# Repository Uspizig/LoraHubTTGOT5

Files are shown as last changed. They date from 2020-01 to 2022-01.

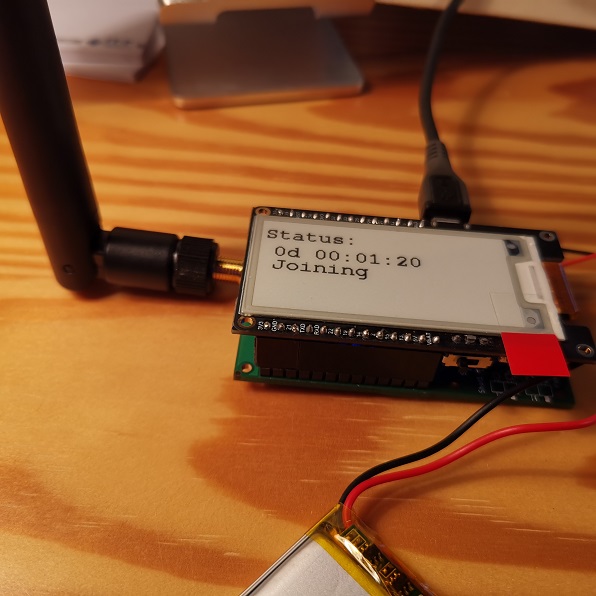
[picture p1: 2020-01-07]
Images/klein_IMG_20200107_193522.jpg

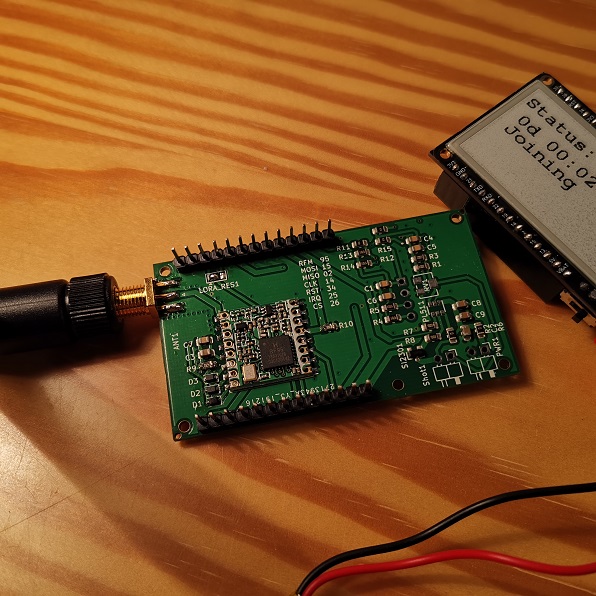
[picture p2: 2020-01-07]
Images/klein_IMG_20200107_193700.jpg

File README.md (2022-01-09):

# LoraHubTTGOT5
Please keep in mind. There are some Limitations in the TTn network right now:
1. For usage with TTN V3: Pease consider this change to avoid unwanted Downlink messages. https://github.com/mcci-catena/arduino-lmic/issues/713 

(Prerequisite: This is my Hobby: No Guarantee for HW or SW. I do not take any responsibility or will help you. This is: "Take it as it is or leave it".)
DO NOT USE THIS in ANY COMMERCIAL PRODUCTS

A LORA TTN Daughter Board for a TTGO T5 Board (http://s.click.aliexpress.com/e/NPRqgBkG) with BME680, BME280, CCS811 and connection possibilities for several other I²C Boards

You might have seen several E-Ink Boards from Waveshare lately. I came across some Boards from TTGO with an ESP32 lately on Aliexpress.
While experimenting with these Boards I tought: Why not add a LORA TTN Chip to these Boards and some other environment sensors.

So here is my try:

You may find in this Repository:
1. Hardware: KiCad & Gerber Files for 
2. SMT Assembly Files for jlcPCB 
3. Pinning: Pin Description
4. Software: A how to make these things running relatively easy in an Arduino IDE

What you need to do to get the SW Running:
1. Clone this Git: https://github.com/ZinggJM/GxEPD2 and install to your Arduino lib folder
2. Replace the two files with the ones provided in GxEPDReplace
3. Install: https://github.com/thesolarnomad/lora-serialization
4. Clone this Git: https://github.com/mcci-catena/arduino-lmic
5A. Make the modifications mentioned in otta SW
5B. Edidt config in the MCCI-Catena to set according yoru Country.
6. Get an App ID, from Thethingsnetwork
7. Check if your area has LORA TTN Coverage
8. Try out one of the examples.

What you need to get the HW:
- TTGO T5 EPaper Board: https://de.aliexpress.com/item/32869729970.html
- RFM95 Lora Chip: https://de.aliexpress.com/item/32831799362.html
- Antenna Connector SMA: http://s.click.aliexpress.com/e/5oGOCiY0
- (OPTIONAL)8dBi Antenna 868MHz: http://s.click.aliexpress.com/e/KVkmsTGG
- (OPTIONAL)TPL5110 for Low Power: http://s.click.aliexpress.com/e/EA7q1R48
- Spacer-Screws: http://s.click.aliexpress.com/e/KejkugSM

Hub Board:
1. Download the Gerber and BOM Files
2. Upload to JLCPCB
3. Select SMT Assembly
4. Solder 3 Diodes, Antenna Connector and RFM Module on the Board
5. (Optional): Solder Battery Connector and TPL5110 Chip on the Board.
6. I made a mistake on the FET and switched Drain and Source pin. You need to make a air wire to fix this if you want to use the TPL5110 RTC.

What you need to Solder
1. RFM95 Chip
2. Antenna Connector
3. 3x Diodes
(Optional) TPL5110 Chip and Battery Connector

Housings:
https://www.thingiverse.com/thing:3462483
https://www.thingiverse.com/thing:4055993

Useful Equipment.:
- Soldering Iron TS100: http://s.click.aliexpress.com/e/Eq2v9g12
- USB Cable: http://s.click.aliexpress.com/e/NiloJfUM
- Soldering Mat. http://s.click.aliexpress.com/e/NAoYAQ5K

My projects are influenced by Dave(G6EJD) and Andreas Spiess. So do me a favor and watch their videos.

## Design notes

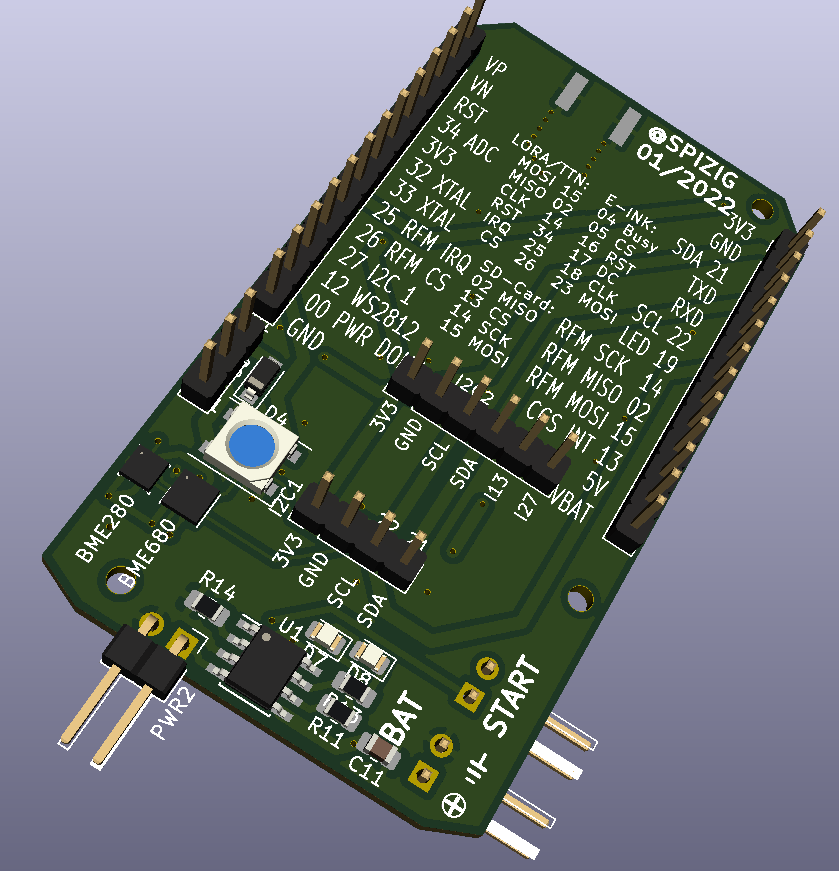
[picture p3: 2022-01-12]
ttgot5 - v2/front.PNG

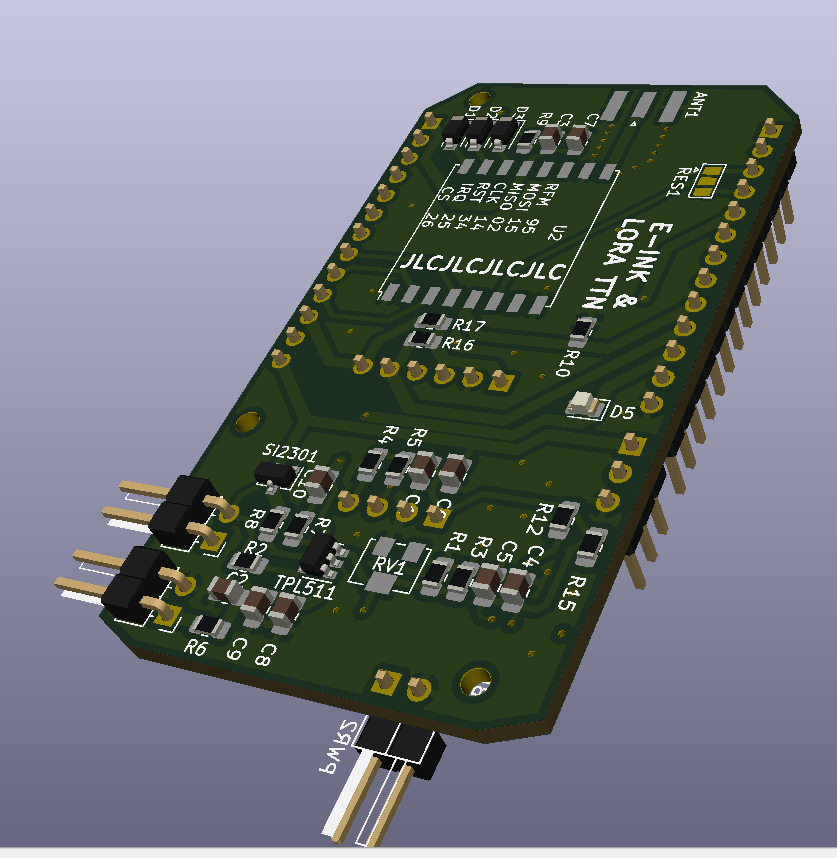
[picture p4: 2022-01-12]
ttgot5 - v2/back.PNG

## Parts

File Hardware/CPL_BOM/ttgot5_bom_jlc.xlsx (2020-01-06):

Comment | Designator | Footprint | LCSC Part #（optional）
100nF | C1 | 0805_C | C49678 (https://lcsc.com/product-detail/Multilayer-Ceramic-Capacitors-MLCC-SMD-SMT_100nF-104-10-50V_C49678.html/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)
22uF | C2 | 0805_C | C45783 (https://lcsc.com/product-detail/Multilayer-Ceramic-Capacitors-MLCC-SMD-SMT_SAMSUNG_CL21A226MAQNNNE_22uF-226-20-25V_C45783.html/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)
1uF | C3 | 0805_C | C28323 (https://lcsc.com/product-detail/Multilayer-Ceramic-Capacitors-MLCC-SMD-SMT_SAMSUNG_CL21B105KBFNNNE_1uF-105-10-50V_C28323.html/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)
100nF | C4 | 0805_C | C49678 (https://lcsc.com/product-detail/Multilayer-Ceramic-Capacitors-MLCC-SMD-SMT_100nF-104-10-50V_C49678.html/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)
100nF | C5 | 0805_C | C49678 (https://lcsc.com/product-detail/Multilayer-Ceramic-Capacitors-MLCC-SMD-SMT_100nF-104-10-50V_C49678.html/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)
100nF | C6 | 0805_C | C49678 (https://lcsc.com/product-detail/Multilayer-Ceramic-Capacitors-MLCC-SMD-SMT_100nF-104-10-50V_C49678.html/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)
100nF | C7 | 0805_C | C49678 (https://lcsc.com/product-detail/Multilayer-Ceramic-Capacitors-MLCC-SMD-SMT_100nF-104-10-50V_C49678.html/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)
1uF | C8 | 0805_C | C28323 (https://lcsc.com/product-detail/Multilayer-Ceramic-Capacitors-MLCC-SMD-SMT_SAMSUNG_CL21B105KBFNNNE_1uF-105-10-50V_C28323.html/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)
100nF | C9 | 0805_C | C28323 (https://lcsc.com/product-detail/Multilayer-Ceramic-Capacitors-MLCC-SMD-SMT_SAMSUNG_CL21B105KBFNNNE_1uF-105-10-50V_C28323.html/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)
1N5819WS | D1 | SOD-323 | C191023 (https://lcsc.com/product-detail/Others_B5819WS_C191023.html/?href=jlc-SMT)
1N5819WS | D2 | SOD-323 | C191023 (https://lcsc.com/product-detail/Others_B5819WS_C191023.html/?href=jlc-SMT)
1N5819WS | D3 | SOD-323 | C191023 (https://lcsc.com/product-detail/Others_B5819WS_C191023.html/?href=jlc-SMT)
TPL5110DDCT | PL511 | TSOT-23-6 | C125830 (https://lcsc.com/product-detail/Timer_TI_TPL5110DDCT_TPL5110DDCT_C125830.html/?href=jlc-SMT)
200K | R1 | 0805_R | C17539 (https://lcsc.com/product-detail/Chip-Resistor-Surface-Mount_Uniroyal-Elec-0805W8F2003T5E_C17539.html/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)
0R | R2 | 0805_R | C17477 (https://lcsc.com/product-detail/Chip-Resistor-Surface-Mount_Uniroyal-Elec-0805W8F0000T5E_C17477.html/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)
200K | R3 | 0805_R | C17539 (https://lcsc.com/product-detail/Chip-Resistor-Surface-Mount_Uniroyal-Elec-0805W8F2003T5E_C17539.html/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)
4.7K | R4 | 0805_R | C17673 (https://lcsc.com/product-detail/Chip-Resistor-Surface-Mount_Uniroyal-Elec-0805W8F4701T5E_C17673.html/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)
4.7K | R5 | 0805_R | C17673 (https://lcsc.com/product-detail/Chip-Resistor-Surface-Mount_Uniroyal-Elec-0805W8F4701T5E_C17673.html/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)
0R | R6 | 0805_R | C17477 (https://lcsc.com/product-detail/Chip-Resistor-Surface-Mount_Uniroyal-Elec-0805W8F0000T5E_C17477.html/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)
100K | R7 | 0805_R | C17407 (https://lcsc.com/product-detail/Chip-Resistor-Surface-Mount_Uniroyal-Elec-0805W8F1003T5E_C17407.html/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)
100K | R8 | 0805_R | C17407 (https://lcsc.com/product-detail/Chip-Resistor-Surface-Mount_Uniroyal-Elec-0805W8F1003T5E_C17407.html/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)
100K | R9 | 0805_R | C17407 (https://lcsc.com/product-detail/Chip-Resistor-Surface-Mount_Uniroyal-Elec-0805W8F1003T5E_C17407.html/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)
100K | R10 | 0805_R | C17407 (https://lcsc.com/product-detail/Chip-Resistor-Surface-Mount_Uniroyal-Elec-0805W8F1003T5E_C17407.html/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)
0R | R11 | 0805_R | C17477 (https://lcsc.com/product-detail/Chip-Resistor-Surface-Mount_Uniroyal-Elec-0805W8F0000T5E_C17477.html/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)
0R | R12 | 0805_R | C17477 (https://lcsc.com/product-detail/Chip-Resistor-Surface-Mount_Uniroyal-Elec-0805W8F0000T5E_C17477.html/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)
4.7K | R13 | 0805_R | C17673 (https://lcsc.com/product-detail/Chip-Resistor-Surface-Mount_Uniroyal-Elec-0805W8F4701T5E_C17673.html/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)
4.7K | R14 | 0805_R | C17673 (https://lcsc.com/product-detail/Chip-Resistor-Surface-Mount_Uniroyal-Elec-0805W8F4701T5E_C17673.html/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)
0R | R15 | 0805_R | C17477 (https://lcsc.com/product-detail/Chip-Resistor-Surface-Mount_Uniroyal-Elec-0805W8F0000T5E_C17477.html/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)
SI2301CDS-T1-GE3 | SI2301 | SOT-23-3 | C10487 (https://lcsc.com/product-detail/MOSFET_Vishay-Intertech_SI2301CDS-T1-GE3_Vishay-Intertech-SI2301CDS-T1-GE3_C10487.html/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)

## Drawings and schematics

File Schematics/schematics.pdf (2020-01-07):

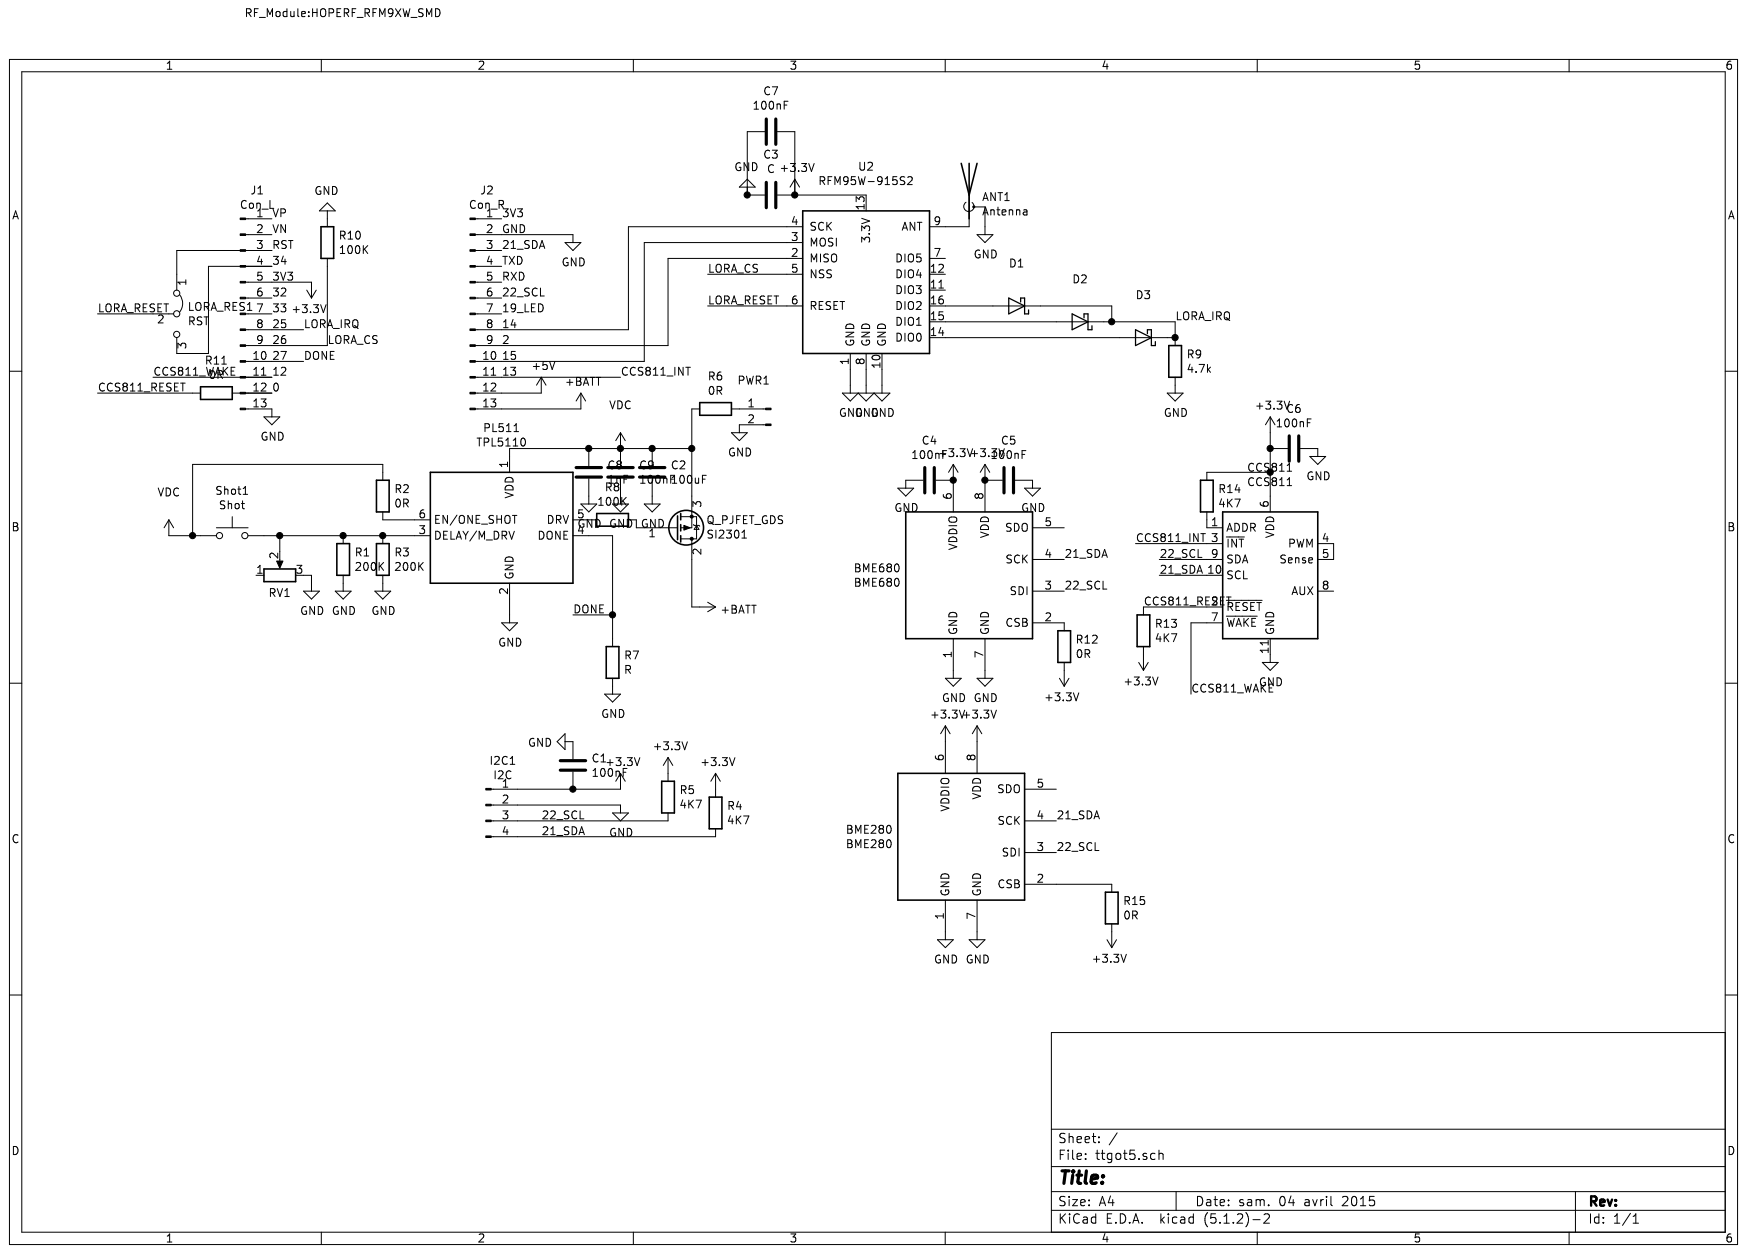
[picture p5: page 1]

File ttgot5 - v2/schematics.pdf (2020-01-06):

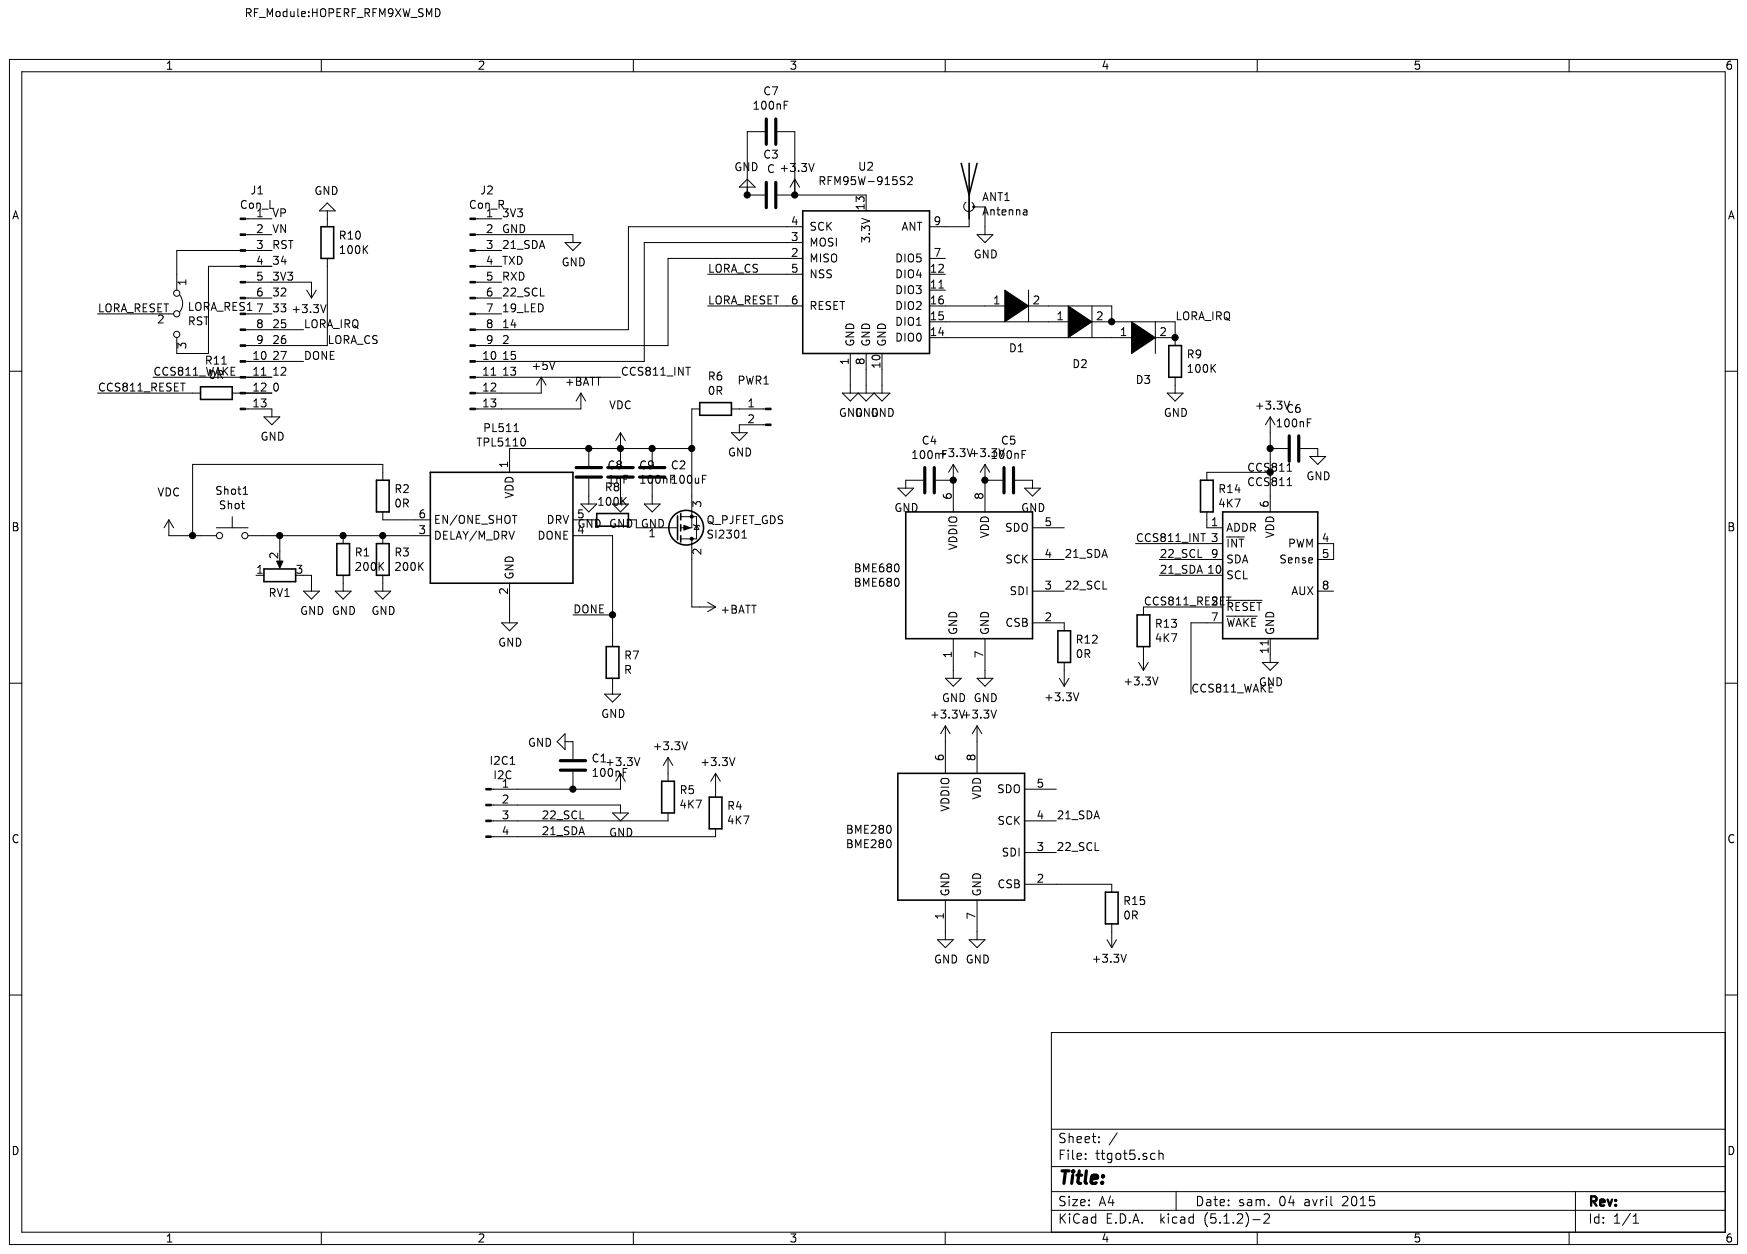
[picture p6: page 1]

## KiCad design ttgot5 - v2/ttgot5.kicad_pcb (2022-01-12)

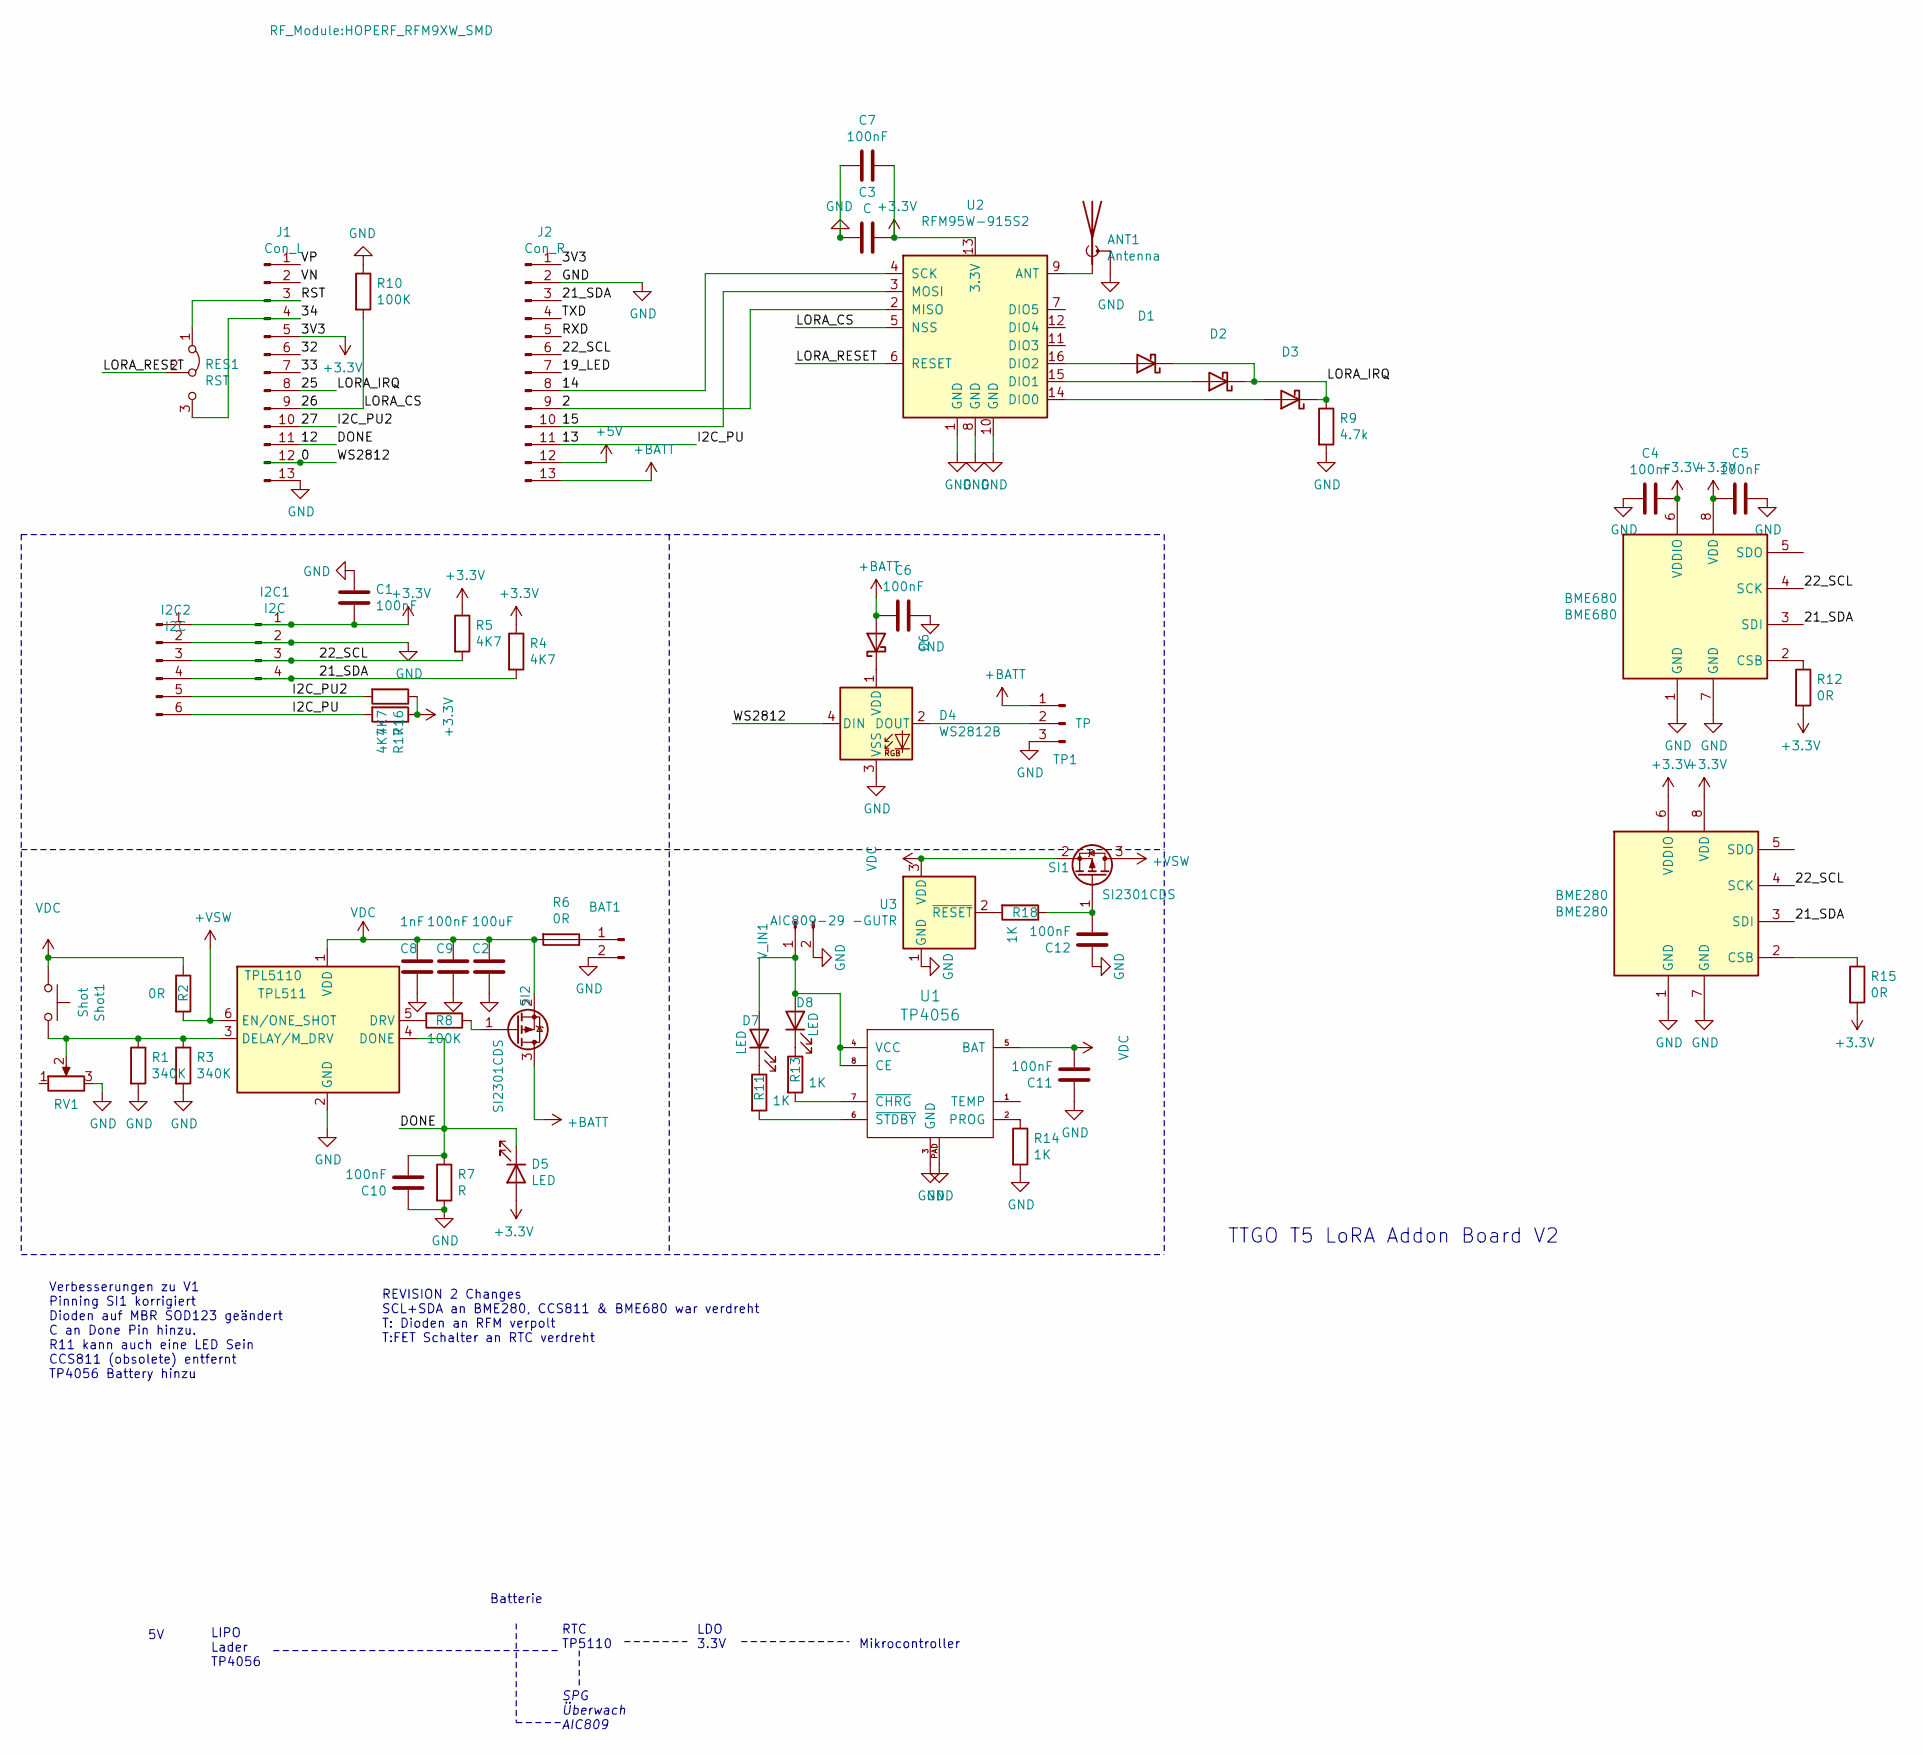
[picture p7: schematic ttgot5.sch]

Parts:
ANT1: Antenna; SMA_Samtec_SMA-J-P-H-ST-EM1_EdgeMount
BAT1: PWR; PinHeader_1x02_P2.54mm_Horizontal
BME280: BME280; Bosch_LGA-8_2.5x2.5mm_P0.65mm_ClockwisePinNumbering
BME680: BME680; Bosch_LGA-8_3x3mm_P0.8mm_ClockwisePinNumbering
C1, C4, C5, C6, C7, C9, C10, C11, C12: 100nF; C_0805_2012Metric_Pad1.15x1.40mm_HandSolder
C2: 100uF; C_0805_2012Metric_Pad1.15x1.40mm_HandSolder
C3: C; C_0805_2012Metric_Pad1.15x1.40mm_HandSolder
C8: 1nF; C_0805_2012Metric_Pad1.15x1.40mm_HandSolder
D1, D2, D3, D6: D; D_SOD-123
D4: WS2812B; LED_WS2812B_PLCC4_5.0x5.0mm_P3.2mm
D5, D7, D8: LED; LED_0805_2012Metric
I2C1: I2C; PinHeader_1x04_P2.54mm_Vertical
I2C2: I2C; PinHeader_1x06_P2.54mm_Vertical
J1: Con_L; PinHeader_1x13_P2.54mm_Vertical
J2: Con_R; PinHeader_1x13_P2.54mm_Vertical
R1, R3: 340K; R_0805_2012Metric_Pad1.15x1.40mm_HandSolder
R2, R6, R12, R15: 0R; R_0805_2012Metric_Pad1.15x1.40mm_HandSolder
R4, R5, R16, R17: 4K7; R_0805_2012Metric_Pad1.15x1.40mm_HandSolder
R7: R; R_0805_2012Metric_Pad1.15x1.40mm_HandSolder
R8, R10: 100K; R_0805_2012Metric_Pad1.15x1.40mm_HandSolder
R9: 4.7k; R_0805_2012Metric_Pad1.15x1.40mm_HandSolder
R11, R13, R14, R18: 1K; R_0805_2012Metric_Pad1.15x1.40mm_HandSolder
RES1: RST; SolderJumper-3_P1.3mm_Bridged12_Pad1.0x1.5mm
RV1: R_POT; Potentiometer_Bourns_3224W_Vertical
SI1, SI2: SI2301CDS; SOT-23
Shot1: Shot; PinHeader_1x02_P2.54mm_Horizontal
TP1: TP; PinHeader_1x03_P2.54mm_Vertical
TPL511: TPL5110; SOT-23-6
U1: TP4056; tp4056
U2: RFM95W-915S2; HOPERF_RFM9XW_SMD
U3: AIC809-29 -GUTR; SOT-23
V_IN1: PWR; PinHeader_1x02_P2.54mm_Horizontal

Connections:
+3V3: BME280.6 (VDDIO), BME280.8 (VDD), BME680.6 (VDDIO), BME680.8 (VDD), C1.2, C3.2, C4.1, C5.2, C7.2, D5.2 (A), I2C1.1, I2C2.1, J1.5, J2.1, R4.1, R5.1, R12.2, R15.2, R16.1, R17.1, U2.13 (3.3V)
+5V: J2.12
+BATT: C6.2, D6.2 (A), J2.13, SI2.3 (D), TP1.1
+VSW: R2.2, SI1.3 (D), TPL511.6 (EN/ONE_SHOT)
/0: D4.4 (DIN), J1.12
/2: J2.9, U2.2 (MISO)
/12: C10.2, D5.1 (K), J1.11, R7.1, TPL511.4 (DONE)
/13: I2C2.6, J2.11, R17.2
/14: J2.8, U2.4 (SCK)
/15: J2.10, U2.3 (MOSI)
/19_LED: J2.7
/21_SDA: BME280.3 (SDI), BME680.3 (SDI), I2C1.4, I2C2.4, J2.3, R4.2
/22_SCL: BME280.4 (SCK), BME680.4 (SCK), I2C1.3, I2C2.3, J2.6, R5.2
/25: D1.1 (K), D2.1 (K), D3.1 (K), J1.8, R9.1
/26: J1.9, R10.2, U2.5 (NSS)
/27: I2C2.5, J1.10, R16.2
/32: J1.6
/33: J1.7
/34: J1.4, RES1.3 (B)
/LORA_RESET: RES1.2 (C), U2.6 (RESET)
/RST: J1.3, RES1.1 (A)
/RXD: J2.5
/TXD: J2.4
/VN: J1.2
/VP: J1.1
GND: ANT1.2 (Shield), BAT1.2, BME280.1 (GND), BME280.7 (GND), BME680.1 (GND), BME680.7 (GND), C1.1, C2.2, C3.1, C4.2, C5.1, C6.1, C7.1, C8.2, C9.2, C10.1, C11.1, C12.1, D4.3 (VSS), I2C1.2, I2C2.2, J1.13, J2.2, R1.2, R3.2, R7.2, R9.2, R10.1, R14.2, RV1.3, TP1.3, TPL511.2 (GND), U1.3 (GND), U1.PAD, U2.1 (GND), U2.8 (GND), U2.10 (GND), U3.1 (GND), V_IN1.2
unnamed: ANT1.1 (A), U2.9 (ANT)
unnamed: BAT1.1, R6.1
unnamed: BME280.2 (CSB), R15.1
unnamed: BME680.2 (CSB), R12.1
unnamed: C12.2, R18.1, SI1.1 (G)
unnamed: D1.2 (A), U2.16 (DIO2)
unnamed: D2.2 (A), U2.15 (DIO1)
unnamed: D3.2 (A), U2.14 (DIO0)
unnamed: D4.1 (VDD), D6.1 (K)
unnamed: D4.2 (DOUT), TP1.2
unnamed: D7.1 (K), R11.1
unnamed: D7.2 (A), D8.2 (A), U1.4 (VCC), U1.8 (CE), V_IN1.1
unnamed: D8.1 (K), R13.1
unnamed: R1.1, R3.1, RV1.2, Shot1.1, TPL511.3 (DELAY/M_DRV)
unnamed: R8.1, SI2.1 (G)
unnamed: R8.2, TPL511.5 (DRV)
unnamed: R11.2, U1.6 (~STDBY)
unnamed: R13.2, U1.7 (~CHRG)
unnamed: R14.1, U1.2 (PROG)
unnamed: R18.2, U3.2 (~RESET)
VDC: C2.1, C8.1, C9.1, C11.2, R2.1, R6.2, SI1.2 (S), SI2.2 (S), Shot1.2, TPL511.1 (VDD), U1.5 (BAT), U3.3 (VDD)

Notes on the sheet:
REVISION 2 Changes SCL+SDA an BME280, CCS811 & BME680 war verdreht T: Dioden an RFM verpolt T:FET Schalter an RTC verdreht
Verbesserungen zu V1 Pinning SI1 korrigiert Dioden auf MBR SOD123 geändert C an Done Pin hinzu. R11 kann auch eine LED Sein CCS811 (obsolete) entfernt TP4056 Battery hinzu
TTGO T5 LoRA Addon Board V2
LIPO Lader TP4056
SPG Überwach AIC809
RTC TP5110
LDO 3.3V
Mikrocontroller
Batterie

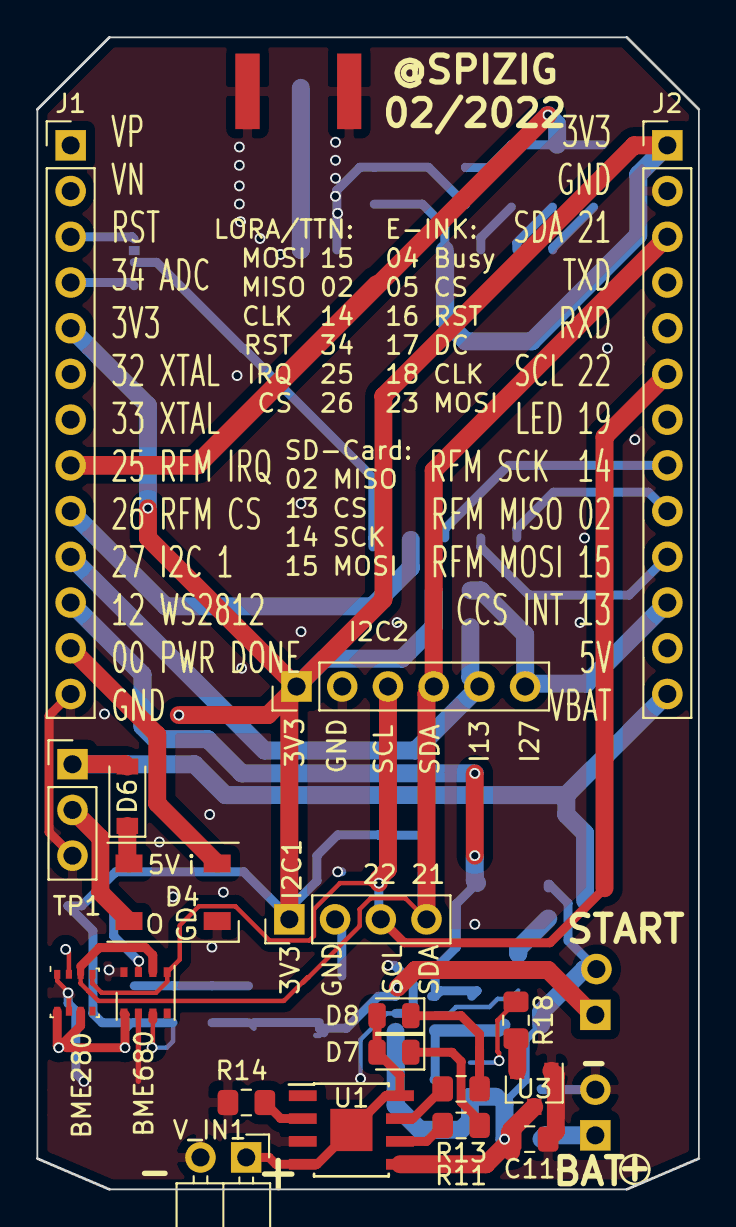
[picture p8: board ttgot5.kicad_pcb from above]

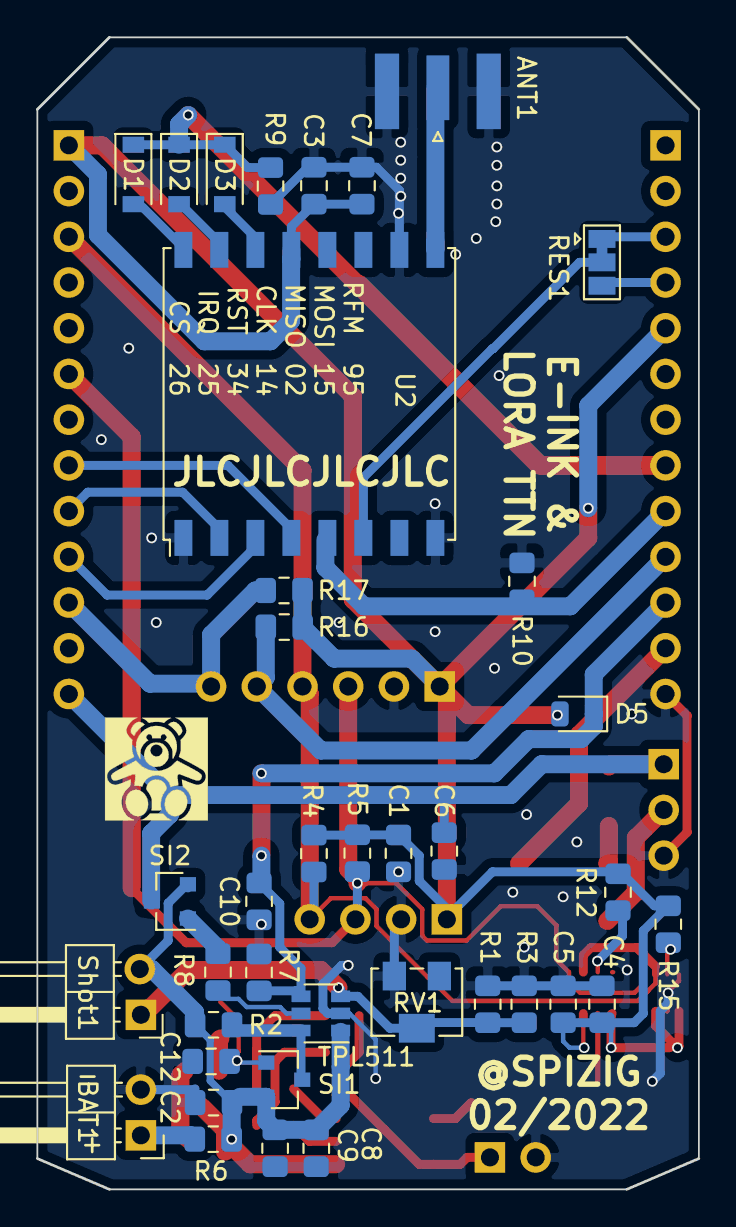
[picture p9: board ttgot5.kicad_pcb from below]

Board: 2 copper layers, 36.8 x 64.0 mm, 57 parts (38 on the bottom side), 39 nets.

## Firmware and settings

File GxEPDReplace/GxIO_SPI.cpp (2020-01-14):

// created by Jean-Marc Zingg to be the GxIO_SPI io class for the GxEPD library
//
// License: GNU GENERAL PUBLIC LICENSE V3, see LICENSE
//

#include "GxIO_SPI.h"

#if defined(PARTICLE)
// transfer16 is not used by GxEPD
#define transfer16 transfer
#endif

#ifdef TTGOT5
GxIO_SPI::GxIO_SPI(SPIClass& einkspi, int8_t cs, int8_t dc, int8_t rst, int8_t bl) :
  _spi(einkspi), _spi_settings(4000000, MSBFIRST, SPI_MODE0),
  _cs(cs), _dc(dc), _rst(rst), _bl(bl)
#else
GxIO_SPI::GxIO_SPI(SPIClass& spi, int8_t cs, int8_t dc, int8_t rst, int8_t bl) :
  _spi(spi), _spi_settings(4000000, MSBFIRST, SPI_MODE0),
  _cs(cs), _dc(dc), _rst(rst), _bl(bl)
{
}
#endif


void GxIO_SPI::reset()
{
  if (_rst >= 0)
  {
    delay(20);
    digitalWrite(_rst, LOW);
    delay(20);
    digitalWrite(_rst, HIGH);
    delay(200);
  }
}

void GxIO_SPI::init()
{
  if (_cs >= 0)
  {
    digitalWrite(_cs, HIGH);
    pinMode(_cs, OUTPUT);
  }
  if (_dc >= 0)
  {
    digitalWrite(_dc, HIGH);
    pinMode(_dc, OUTPUT);
  }
  if (_rst >= 0)
  {
    digitalWrite(_rst, HIGH);
    pinMode(_rst, OUTPUT);
  }
  if (_bl >= 0)
  {
    digitalWrite(_bl, HIGH);
    pinMode(_bl, OUTPUT);
  }
  reset();
  _spi.begin();
}

void GxIO_SPI::setFrequency(uint32_t freq)
{
  _spi_settings = SPISettings(freq, MSBFIRST, SPI_MODE0);
}

uint8_t GxIO_SPI::transferTransaction(uint8_t d)
{
  _spi.beginTransaction(_spi_settings);
  if (_cs >= 0) digitalWrite(_cs, LOW);
  uint8_t rv = _spi.transfer(d);
  if (_cs >= 0) digitalWrite(_cs, HIGH);
  _spi.endTransaction();
  return rv;
}

uint16_t GxIO_SPI::transfer16Transaction(uint16_t d)
{
  _spi.beginTransaction(_spi_settings);
  if (_cs >= 0) digitalWrite(_cs, LOW);
  uint16_t rv = _spi.transfer16(d);
  if (_cs >= 0) digitalWrite(_cs, HIGH);
  _spi.endTransaction();
  return rv;
}

uint8_t GxIO_SPI::readDataTransaction()
{
  _spi.beginTransaction(_spi_settings);
  if (_cs >= 0) digitalWrite(_cs, LOW);
  uint8_t rv = _spi.transfer(0xFF);
  if (_cs >= 0) digitalWrite(_cs, HIGH);
  _spi.endTransaction();
  return rv;
}

uint16_t GxIO_SPI::readData16Transaction()
{
  _spi.beginTransaction(_spi_settings);
  if (_cs >= 0) digitalWrite(_cs, LOW);
  uint16_t rv = _spi.transfer16(0xFFFF);
  if (_cs >= 0) digitalWrite(_cs, HIGH);
  _spi.endTransaction();
  return rv;
}

uint8_t GxIO_SPI::readData()
{
  uint8_t rv = _spi.transfer(0xFF);
  return rv;
}

uint16_t GxIO_SPI::readData16()
{
  uint16_t rv = _spi.transfer16(0xFFFF);
  return rv;
}

void GxIO_SPI::writeCommandTransaction(uint8_t c)
{
  _spi.beginTransaction(_spi_settings);
  if (_dc >= 0) digitalWrite(_dc, LOW);
  if (_cs >= 0) digitalWrite(_cs, LOW);
  _spi.transfer(c);
  if (_cs >= 0) digitalWrite(_cs, HIGH);
  if (_dc >= 0) digitalWrite(_dc, HIGH);
  _spi.endTransaction();
}

void GxIO_SPI::writeDataTransaction(uint8_t d)
{
  _spi.beginTransaction(_spi_settings);
  if (_cs >= 0) digitalWrite(_cs, LOW);
  _spi.transfer(d);
  if (_cs >= 0) digitalWrite(_cs, HIGH);
  _spi.endTransaction();
}

void GxIO_SPI::writeData16Transaction(uint16_t d, uint32_t num)
{
  _spi.beginTransaction(_spi_settings);
  if (_cs >= 0) digitalWrite(_cs, LOW);
  writeData16(d, num);
  if (_cs >= 0) digitalWrite(_cs, HIGH);
  _spi.endTransaction();
}

void GxIO_SPI::writeCommand(uint8_t c)
{
  if (_dc >= 0) digitalWrite(_dc, LOW);
  _spi.transfer(c);
  if (_dc >= 0) digitalWrite(_dc, HIGH);
}

void GxIO_SPI::writeData(uint8_t d)
{
  _spi.transfer(d);
}

void GxIO_SPI::writeData(uint8_t* d, uint32_t num)
{
#if defined(ESP8266) || defined(ESP32)
  _spi.writeBytes(d, num);
#else
  while (num > 0)
  {
    _spi.transfer(*d);
    d++;
    num--;
  }
#endif
}

void GxIO_SPI::writeData16(uint16_t d, uint32_t num)
{
#if defined(ESP8266) || defined(ESP32)
  uint8_t b[2] = {uint8_t(d >> 8), uint8_t(d)};
  _spi.writePattern(b, 2, num);
#else
  while (num > 0)
  {
    _spi.transfer16(d);
    num--;
  }
#endif
}

void GxIO_SPI::writeAddrMSBfirst(uint16_t d)
{
  _spi.transfer(d >> 8);
  _spi.transfer(d & 0xFF);
}

void GxIO_SPI::startTransaction()
{
  _spi.beginTransaction(_spi_settings);
  if (_cs >= 0) digitalWrite(_cs, LOW);
}

void GxIO_SPI::endTransaction()
{
  if (_cs >= 0) digitalWrite(_cs, HIGH);
  _spi.endTransaction();
}

void GxIO_SPI::selectRegister(bool rs_low)
{
  if (_dc >= 0) digitalWrite(_dc, (rs_low ? LOW : HIGH));
}

void GxIO_SPI::setBackLight(bool lit)
{
  if (_bl >= 0) digitalWrite(_bl, (lit ? HIGH : LOW));
}

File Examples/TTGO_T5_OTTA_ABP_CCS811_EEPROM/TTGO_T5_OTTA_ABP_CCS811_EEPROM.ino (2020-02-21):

//Test Eink und MCCi Lora mit TTGO T5 Board
//Join nach 2-3 Versuchen 
// Works: Speichert Join Daten in RTC Memory und EEPROM
// Works: Lese Join Daten aus RTC Memory.
// Displays Data on a 2.13 Eink Display TTGOT5
// Geraet3 ist ohne Display! mit BME280, mit CCS811
// Geraet2 mit BME280
// Geraet1 mit BMP280


//Notwendige Änderungen in der Stack:
//#define LMICbandplan_getInitialDrJoin() (EU868_DR_SF8) in lmic_bandplan_eu868.h
//#define LMIC_PRINTF_TO Serial //USpizig  in config.h bringt aber keinerlei zusätzliche debug Ausgaben
//in config.h Debug Messages an und RFM95 fediniert
//in oslmic.h ersetze #define OSTICKS_PER_SEC von 32768 in 50000 //Uspizig bringt aber nix
//in hal.cpp replaced spi-begin to spi.begin(14, 2, 15, 26); to match pinning
/*
static void hal_spi_init () {
    //SPI.begin();//Original
  //SPI.begin(lmic_pins.sck, lmic_pins.miso, lmic_pins.mosi, lmic_pins.nss);
  SPI.begin(14, 2, 15, 26);
}
*/


//for Debugging
//#define SingleChannelMode 1 //to check on own gateway Join Behaviour
#define LMIC_DEBUG_LEVEL 1
#define geraet1 //soldered DIO0 directly to GPIO 34 and DIO01 to GPIO25  == Board identifies as COM26
//#define geraet2 //Both DIO00 and DIO01 soldered with a Diode to GPIO 25  == Board identifies as COM7
//#define geraet3 //ESP32 TTGO Mini V2 COM9


// How often to send a packet. Note that this sketch bypasses the normal
// LMIC duty cycle limiting, so when you change anything in this sketch
// (payload length, frequency, spreading factor), be sure to check if
// this interval should not also be increased.
// See this spreadsheet for an easy airtime and duty cycle calculator:
// https://docs.google.com/spreadsheets/d/1voGAtQAjC1qBmaVuP1ApNKs1ekgUjavHuVQIXyYSvNc  
// Schedule TX every this many seconds (might become longer due to duty
// cycle limitations).

#ifdef geraet1
  const unsigned TX_INTERVAL = 60; 
  #define BMP_ADRESS 0x76
  #define BMP280_CONNECTED //geraet1
#endif
#ifdef geraet2 //limit uplinks on testboard
  const unsigned TX_INTERVAL = 180; 
  #define BMP_ADRESS 0x76
  #define BMP280_CONNECTED //geraet1
#endif
#ifdef geraet3 //limit uplinks on testboard
  const unsigned TX_INTERVAL = 45; 
  #define BME280_CONNECTED
  #define BME_ADRESS 0x77
  #define CCS811_CONNECTED
  #define CCS811_ADRESS 0x5A
#endif

//const unsigned long UpdateInterval = (60L * 20L - 03) * 1000000L; // Update delay in microseconds
#define uS_TO_S_FACTOR 1000000  /* Conversion factor for micro seconds to seconds */
#define TIME_TO_SLEEP  60        /* Time ESP32 will go to sleep (in seconds) */

//WetterSymbols Size
int wettercount = 1;
#define LEFT 1
#define CENTER 2
#define RIGHT 3
boolean LargeIcon = true, SmallIcon = false;
//250x122 Pixel
int wetter_symbol_x = 210; 
int wetter_symbol_y = 30; 
int status_symbol_x = 210;
int status_symbol_y = 122;
boolean wetter_symbol_size = true;
#define Large  5           // For icon drawing, needs to be odd number for best effect
#define Small  3            // For icon drawing, needs to be odd number for best effect

#ifdef geraet1
//Check here your Version and Pinnings
  #define TTGOT5 1 //neded to indicate the E-INK Library a different pinning
  #define E_INK_PIN_SPI_BUSY 4//19
  #define E_INK_PIN_SPI_RST  16//21
  #define E_INK_PIN_SPI_DC   17//22
  #define E_INK_PIN_SPI_CS   5
  #define E_INK_PIN_SPI_DIN  23
  #define E_INK_PIN_SPI_SCK  18 
  #define E_INK_PIN_SPI_MISO 24//n/A

//Lora Pinning for TTGO T5 Addon Board
  #define LORA_PIN_SPI_MOSI 15//19
  #define LORA_PIN_SPI_MISO 2//n/A
  #define LORA_PIN_SPI_SCK  14
  #define LORA_PIN_SPI_NSS  26  
  #define LORA_PIN_SPI_RST  33  
  #define LORA_PIN_SPI_DIO1 25
  #define LORA_PIN_SPI_DIO0 34
#endif
#ifdef geraet2
  #define TTGOT5 1 //neded to indicate the E-INK Library a different pinning
  #define E_INK_PIN_SPI_BUSY 4//19
  #define E_INK_PIN_SPI_RST  16//21
  #define E_INK_PIN_SPI_DC   17//22
  #define E_INK_PIN_SPI_CS   5
  #define E_INK_PIN_SPI_DIN  23
  #define E_INK_PIN_SPI_SCK  18 
  #define E_INK_PIN_SPI_MISO 24//n/A

//Lora Pinning for TTGO T5 Addon Board
  #define LORA_PIN_SPI_MOSI 15//19
  #define LORA_PIN_SPI_MISO 2//n/A
  #define LORA_PIN_SPI_SCK  14
  #define LORA_PIN_SPI_NSS  26  
  #define LORA_PIN_SPI_RST  33  
  #define LORA_PIN_SPI_DIO1 25
  #define LORA_PIN_SPI_DIO0 34
#endif
#ifdef geraet3 //ESP32 TTGO MINI V2
//Check here your Version and Pinnings
  #define TTGOT5 1 //neded to indicate the E-INK Library a different pinning
  #define E_INK_PIN_SPI_BUSY 4
  #define E_INK_PIN_SPI_RST  16
  #define E_INK_PIN_SPI_DC   17
  #define E_INK_PIN_SPI_CS   13
  #define E_INK_PIN_SPI_DIN  23
  #define E_INK_PIN_SPI_SCK  18 
  #define E_INK_PIN_SPI_MISO 24//n/A

//Lora Pinning for TTGO ESP32 Mini V2 mit EINK+Lora Addon Board
  #define LORA_PIN_SPI_MOSI 5
  #define LORA_PIN_SPI_MISO 19
  #define LORA_PIN_SPI_SCK  18//14 = 1 Jumperstellung //18 = 3 Jumperstellung
  #define LORA_PIN_SPI_NSS  26  
  #define LORA_PIN_SPI_RST  33  
  #define LORA_PIN_SPI_DIO1 27
  #define LORA_PIN_SPI_DIO0 27
#endif


//Battery Pin
  #define BATTERY_PIN 35
  
#include <lmic.h>
#include <hal/hal.h>
#include <SPI.h>
#include <EEPROM.h>

//#include "LoraEncoder.h"
#include <LoraMessage.h>

//Temperatur:
#include <Wire.h>
#ifdef BMP280_CONNECTED
  #include <Adafruit_BMP280.h>
  Adafruit_BMP280 bmp; // I2C
#endif

#ifdef BME280_CONNECTED
  #define SEALEVELPRESSURE_HPA (1013.25)
  #include <Adafruit_BME280.h>
  Adafruit_BME280 bme;
#endif

#ifdef CCS811_CONNECTED 
  #include <SparkFunCCS811.h> //Click here to get the library: http://librarymanager/All#SparkFun_CCS811
  CCS811 myCCS811(CCS811_ADRESS);
#endif


#ifdef geraet3
  #define sda 21 ///* I2C Pin Definition */
  #define scl 22 ///* I2C Pin Definition */
#else
  #define sda 21 ///* I2C Pin Definition */
  #define scl 22 ///* I2C Pin Definition */
#endif

float temp = 23;
float pressure = 980;
float humidity = 50;
float ccs811_CO2 = 450;
float ccs811_TVOC = 2;

/*EINK Teile*/

#include <GxEPD2_BW.h>
#include <GxEPD2_3C.h>
#include "GxEPD2_boards_added.h"
// select one and adapt to your mapping, can use full buffer size (full HEIGHT)
//GxEPD2_BW<GxEPD2_213, GxEPD2_213::HEIGHT> display(GxEPD2_213(/*CS=5*/ SS, /*DC=*/ 17, /*RST=*/ 16, /*BUSY=*/ 4)); // GDE0213B1, phased out
//GxEPD2_BW<GxEPD2_213_B72, GxEPD2_213_B72::HEIGHT> display(GxEPD2_213_B72(/*CS=5*/ SS, /*DC=*/ 17, /*RST=*/ 16, /*BUSY=*/ 4)); // GDEH0213B72
//GxEPD2_BW<GxEPD2_213_flex, GxEPD2_213_flex::HEIGHT> display(GxEPD2_213_flex(/*CS=5*/ SS, /*DC=*/ 17, /*RST=*/ 16, /*BUSY=*/ 4)); // GDEW0213I5F
//GxEPD2_BW<GxEPD2_290, GxEPD2_290::HEIGHT> display(GxEPD2_290(/*CS=5*/ SS, /*DC=*/ 17, /*RST=*/ 16, /*BUSY=*/ 4));
//GxEPD2_BW<GxEPD2_290_T5, GxEPD2_290_T5::HEIGHT> display(GxEPD2_290_T5(/*CS=5*/ SS, /*DC=*/ 17, /*RST=*/ 16, /*BUSY=*/ 4)); // GDEW029T5
//GxEPD2_BW<GxEPD2_it60, GxEPD2_it60::HEIGHT> display(GxEPD2_it60(/*CS=5*/ SS, /*DC=*/ 17, /*RST=*/ 16, /*BUSY=*/ 4));

#ifdef geraet3
  //GxEPD2_BW<GxEPD2_290, GxEPD2_290::HEIGHT> display(GxEPD2_290(/*CS=5*/ E_INK_PIN_SPI_CS, /*DC=*/ E_INK_PIN_SPI_DC, /*RST=*/ E_INK_PIN_SPI_RST, /*BUSY=*/  E_INK_PIN_SPI_BUSY));
  //GxEPD2_3C<GxEPD2_270c, GxEPD2_270c::HEIGHT> display(GxEPD2_270c(/*CS=5*/ E_INK_PIN_SPI_CS, /*DC=*/ E_INK_PIN_SPI_DC, /*RST=*/ E_INK_PIN_SPI_RST, /*BUSY=*/ E_INK_PIN_SPI_BUSY));
  //GxEPD2_BW<GxEPD2_290_T5, GxEPD2_290_T5::HEIGHT> display(GxEPD2_290_T5(/*CS=5*/ E_INK_PIN_SPI_CS, /*DC=*/ E_INK_PIN_SPI_DC, /*RST=*/ E_INK_PIN_SPI_RST, /*BUSY=*/ E_INK_PIN_SPI_BUSY));
  GxEPD2_BW<GxEPD2_213_B73, GxEPD2_213_B73::HEIGHT> display(GxEPD2_213_B73(/*CS=5*/ E_INK_PIN_SPI_CS, /*DC=*/ E_INK_PIN_SPI_DC, /*RST=*/ E_INK_PIN_SPI_RST, /*BUSY=*/ E_INK_PIN_SPI_BUSY)); // GDEH0213B73
#else
  GxEPD2_BW<GxEPD2_213_B73, GxEPD2_213_B73::HEIGHT> display(GxEPD2_213_B73(/*CS=5*/ E_INK_PIN_SPI_CS, /*DC=*/ E_INK_PIN_SPI_DC, /*RST=*/ E_INK_PIN_SPI_RST, /*BUSY=*/ E_INK_PIN_SPI_BUSY)); // GDEH0213B73
#endif


//Wifi
#include "WiFi.h"

// FreeFonts from Adafruit_GFX
#include <Fonts/FreeMonoBold9pt7b.h>
#include <Fonts/FreeMonoBold12pt7b.h>
#include <Fonts/FreeMonoBold18pt7b.h>
#include <Fonts/FreeMonoBold24pt7b.h>



uint32_t start_time;
uint32_t next_time;
uint32_t previous_time;
uint32_t previous_full_update;

uint32_t total_seconds = 0;
uint32_t startup_seconds = 0;
uint32_t seconds, minutes, hours, days;

uint32_t join_total_seconds = 0;
uint32_t join_seconds, join_minutes, join_hours, join_days;

//Partial Update:
const uint32_t partial_update_period_s = 30;
//const uint32_t full_update_period_s = 60 * 60 * 60;//alle 2.5 Tage
const uint32_t full_update_period_s = 60 * 60;//(jede Stunde)
//const uint32_t full_update_period_s = 60;(jede Minute)
/*EINK Teile ENDE*/

//Variables for ABP after OTAA Join
u1_t NWKSKEY[16] ;                               // LoRaWAN NwkSKey, network session key.
u1_t APPSKEY[16] ;                               // LoRaWAN AppSKey, application session key.
u4_t DEVADDR ;

#ifdef geraet1
  #define DATAVALID 0xACF2AFC2//1                     // Pattern for data valid in EEPROM/RTC memory
#endif
#ifdef geraet2
  #define DATAVALID 0xACF2AFC2//3                     // Pattern for data valid in EEPROM/RTC memory
#endif
#ifdef geraet3
  #define DATAVALID 0xACF2AFCA                     // Pattern for data valid in EEPROM/RTC memory
#endif

//RealTimeVariables which don't get erased during Sleep
  struct Daten_struct {//https://esp32.com/viewtopic.php?t=11984
    uint16_t Stack[15];
    uint8_t Counter_History;
  };
  RTC_DATA_ATTR uint32_t SAVED_dataValid ;                           // DATAVALID if valid data (joined)
  RTC_DATA_ATTR uint8_t  SAVED_devaddr[4] ;                          // Device address after join
  RTC_DATA_ATTR uint8_t  SAVED_nwkKey[16] ;                          // Network session key after join
  RTC_DATA_ATTR uint8_t  SAVED_artKey[16] ;                          // Aplication session key after join
  RTC_DATA_ATTR uint32_t SAVED_seqnoUp ;                             // Sequence number       
  bool OTAA = true ;   //startup with OTAA if No EEPROM was Saved before
  //History of Data
  RTC_DATA_ATTR  struct Daten_struct Druck_Werte;                 
  RTC_DATA_ATTR  struct Daten_struct Temp_Werte;
  RTC_DATA_ATTR  struct Daten_struct CO2_Werte;
  RTC_DATA_ATTR  struct Daten_struct TVOC_Werte;                                                   
  RTC_DATA_ATTR  struct Daten_struct Feuchte_Werte;

//variables for OTAA JOIN
#ifdef geraet1
//LORA Keys 1
//Lora APP ID 012345
  static const u1_t PROGMEM APPEUI[8]={ xxx };//lsb
  void os_getArtEui (u1_t* buf) { memcpy_P(buf, APPEUI, 8);}
  
  static const u1_t PROGMEM DEVEUI[8]={ xxx};//lsb
  void os_getDevEui (u1_t* buf) { memcpy_P(buf, DEVEUI, 8);}

  //msb
  static const u1_t PROGMEM APPKEY[16] = { xxx1 };
  void os_getDevKey (u1_t* buf) {  memcpy_P(buf, APPKEY, 16);}
#endif
#ifdef geraet2
//LORA Keys 2
//Lora App ID 02
  static const u1_t PROGMEM APPEUI[8]={ xxx};
  void os_getArtEui (u1_t* buf) { memcpy_P(buf, APPEUI, 8);}
  
  static const u1_t PROGMEM DEVEUI[8]={ xxx };
  void os_getDevEui (u1_t* buf) { memcpy_P(buf, DEVEUI, 8);}
  
  static const u1_t PROGMEM APPKEY[16] = {xxx };
  void os_getDevKey (u1_t* buf) {  memcpy_P(buf, APPKEY, 16);}
#endif
#ifdef geraet3
  
  //sensornet_ccs811_bme280_ App 03
  static const u1_t PROGMEM APPEUI[8]={ xxx };
  void os_getArtEui (u1_t* buf) { memcpy_P(buf, APPEUI, 8);}
  
  static const u1_t PROGMEM DEVEUI[8]={ xxx };
  void os_getDevEui (u1_t* buf) { memcpy_P(buf, DEVEUI, 8);}
  
  static const u1_t PROGMEM APPKEY[16] = { xxx };
  void os_getDevKey (u1_t* buf) {  memcpy_P(buf, APPKEY, 16);}
#endif


int verbunden_indicator = 0;
int Packet_Transmission_ongoing = 0; // Display wird nur aktualisiert wenn kein Paket gesendet wird
int packet_counter =0;
int packet_counter_rx =0;
static osjob_t sendjob;
devaddr_t DeviceName = 0;

// Pin mapping

const lmic_pinmap lmic_pins = {
    .nss = LORA_PIN_SPI_NSS,
    .rxtx = LMIC_UNUSED_PIN,
    .rst = LMIC_UNUSED_PIN,
    #ifdef geraet1
      .dio = {LORA_PIN_SPI_DIO0, LORA_PIN_SPI_DIO1, LMIC_UNUSED_PIN}, 
    #else
      .dio = {LORA_PIN_SPI_DIO1, LORA_PIN_SPI_DIO1, LMIC_UNUSED_PIN}, 
    #endif
    /*
    //workaround to use 1 pin for all 3 radio dio pins
    // optional: set polarity of rxtx pin.
    .rxtx_rx_active = 0,
    // optional: set RSSI cal for listen-before-talk
    // this value is in dB, and is added to RSSI
    // measured prior to decision.
    // Must include noise guardband! Ignored in US,
    // EU, IN, other markets where LBT is not required.
    .rssi_cal = 0,
    // optional: override LMIC_SPI_FREQ if non-zero
    .spi_freq = 0,*/
    .rxtx_rx_active = 0,//kopiert von TTGO Board
    .rssi_cal = 10,//kopiert von TTGO Board
    //.spi_freq = 8000000, /* 8MHz */ //kopiert von TTGO Board
    .spi_freq = 4000000, //4 MHZ from GxEPD2 https://github.com/ZinggJM/GxEPD2/tree/master/extras/sw_spi
};



void printHex2(unsigned v) {
    v &= 0xff;
    if (v < 16)
        Serial.print('0');
    Serial.print(v, HEX);
}
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
void loop() {
    os_runloop_once();
    if (verbunden_indicator == 4){
      verbunden_indicator = 2;
       #ifdef BMP280_CONNECTED
            Serial.print(" next_time:");Serial.println(next_time);
            BMP_Test();
          #endif
          #ifdef BME280_CONNECTED
            BME_Test();
       #endif
       #ifdef CCS811_CONNECTED
          CCS811_Test();
       #endif
       #ifdef geraet3
         //do not use display
       #else
          //showPartialUpdate(); 
          showPartialUpdateWetter(wetter_symbol_x, wetter_symbol_y, wetter_symbol_size);
       #endif
       //begin_sleep();
    }
}



//Parts below this line can be used independent from LORA and are only for displaying Stuff on the EINK
void showPartialUpdateWetter(int x, int y, boolean IconSize){
 int box_w = 70;
 int box_h = 65;
 //boolean IconSize = false;
 display.fillRect(x-30, y-25, box_w, box_h, GxEPD_WHITE);
 display.drawRect(x-30, y-25, box_w, box_h, GxEPD_BLACK);
 
 if (wettercount <12){  
  if (wettercount == 1) Sunny(x, y, IconSize, "01d");
  else if (wettercount == 2)  MostlySunny(x, y, IconSize, "02d");
  else if (wettercount == 3)  Cloudy(x, y, IconSize, "03d");
  else if (wettercount == 4)  MostlySunny(x, y, IconSize, "04d");
  else if (wettercount == 5)  ChanceRain(x, y, IconSize, "09d");
  else if (wettercount == 6)  Rain(x, y, IconSize, "10d");
  else if (wettercount == 7)  Tstorms(x, y, IconSize, "11d");
  else if (wettercount == 8)  Snow(x, y, IconSize, "13d");
  else if (wettercount == 9)  Haze(x, y, IconSize, "50d");
  else if (wettercount == 10) Fog(x, y, IconSize, "50n");
  else                        Nodata(x, y, IconSize, "55d");
  wettercount++;
  //Serial.print("Wetter-Symbol:");Serial.println(wettercount);
 }
 else{
  wettercount = 1;
 }
 Temp_Anzeige(x-20, y+15, IconSize); // externe Temperatur
 #ifdef BMP280_CONNECTED
  AQI_Anzeige(x-20, y+54, IconSize);
 //#endif
 //#ifdef CCS811_CONNECTED
    Verlauf_Anzeige(x-91, y+53, IconSize, &Temp_Werte, "Temp:");
    Verlauf_Anzeige(x-91, y-10, IconSize, &Druck_Werte, "Druck:");
    
    //Druck_Verlauf_Anzeige(x-91, y+53, IconSize);//unten
    //Druck_Verlauf_Anzeige(x-91, y-10, IconSize);//oben
 #endif
 TX_Anzeige(x-201, y+78, IconSize); 
 Online_Anzeige(x-201, y+58, IconSize);
 Temp_Anzeige_Main(x-181, y+2, IconSize);
 display.setFullWindow();
 display.display(true);
}

void AQI_Anzeige(int x, int y, boolean IconSize){
   int box_w = 70;
   int box_h = 40;
   display.fillRect(x-10, y-13, box_w, box_h, GxEPD_WHITE);
   display.drawRect(x-10, y-13, box_w, box_h, GxEPD_BLACK);
   display.setFont(&FreeMonoBold9pt7b);
   display.setCursor(x, y); display.print("AQI:"); 
   display.setCursor(x, y+20); display.print(temp); 
}

void Druck_Verlauf_Anzeige(int x, int y, boolean IconSize){
   int box_w = 70;
   int box_h = 58;
   int x2 = x-9;
   
   display.fillRect(x-10, y-13, box_w, box_h, GxEPD_WHITE);
   display.drawRect(x-10, y-13, box_w, box_h, GxEPD_BLACK);
   display.setFont(&FreeMonoBold9pt7b);

   for (int i = 0; i < 14; i++){
      int delta = 45 - Temp_Werte.Stack[i];
      display.fillRect(x2+i*5,  y+2, 4, 45,        GxEPD_BLACK);//1
      display.fillRect(x2+i*5,  y+2, 4, (45-delta),GxEPD_WHITE);//1
      //display.setCursor(x2+i*5, y+10); display.print(i); 
   }   
   /*display.fillRect(x2-10,  y+10, 4, 30, GxEPD_BLACK);//1
   display.fillRect(x2-5,  y+10, 4, 30, GxEPD_BLACK);//2
   display.fillRect(x2,    y+10, 4, 30, GxEPD_BLACK);//3
   display.fillRect(x2+5,  y+10, 4, 30, GxEPD_BLACK);//4
   display.fillRect(x2+10, y+10, 4, 30, GxEPD_BLACK);//5
   display.fillRect(x2+15, y+10, 4, 30, GxEPD_BLACK);//6
   display.fillRect(x2+20, y+10, 4, 30, GxEPD_BLACK);//7
   display.fillRect(x2+25, y+10, 4, 30, GxEPD_BLACK);//8
   display.fillRect(x2+30, y+10, 4, 30, GxEPD_BLACK);//9
   display.fillRect(x2+35, y+10, 4, 30, GxEPD_BLACK);//10
   display.fillRect(x2+40, y+10, 4, 30, GxEPD_BLACK);//11
   display.fillRect(x2+45, y+10, 4, 30, GxEPD_BLACK);//12
   display.fillRect(x2+50, y+10, 4, 30, GxEPD_BLACK);//13
   //display.fillRect(x2+55, y+10, 4, 30, GxEPD_BLACK);//14

   
   display.fillRect(x2-10,  y+10, 4, 15,GxEPD_WHITE);//1
   display.fillRect(x2-5,  y+10, 4, 25, GxEPD_WHITE);//2
   display.fillRect(x2,    y+10, 4, 10, GxEPD_WHITE);//3
   display.fillRect(x2+5,  y+10, 4,  5, GxEPD_WHITE);//4
   display.fillRect(x2+10, y+10, 4, 15, GxEPD_WHITE);//5
   display.fillRect(x2+15, y+10, 4, 25, GxEPD_WHITE);//6
   display.fillRect(x2+20, y+10, 4, 10, GxEPD_WHITE);//7
   display.fillRect(x2+25, y+10, 4,  5, GxEPD_WHITE);//8
   display.fillRect(x2+30, y+10, 4, 15, GxEPD_WHITE);//9
   display.fillRect(x2+35, y+10, 4, 10, GxEPD_WHITE);//10
   display.fillRect(x2+40, y+10, 4, 5, GxEPD_WHITE);//11
   display.fillRect(x2+45, y+10, 4, 25, GxEPD_WHITE);//12
   display.fillRect(x2+50, y+10, 4, 5, GxEPD_WHITE);//13
   //display.fillRect(x2+55, y+10, 4, 25, GxEPD_WHITE);//14
   */
   display.setFont(&FreeMonoBold9pt7b);
   display.setCursor(x-5, y); display.print("Druck:"); 
}

void Verlauf_Anzeige(int x, int y, boolean IconSize, struct Daten_struct *daten, const char* header){
   int box_w = 70;
   int box_h = 58;
   int x2 = x-9;
   int y2 = y+10;
   int max_value = 0;
   int min_value = 1500;
   int range = 30;

   for (int i = 0; i < 14; i++){//Finde max und Min Value
      if (daten->Stack[i] > max_value) max_value = daten->Stack[i];
      if (daten->Stack[i] < min_value) min_value = daten->Stack[i];
   }
   
   display.fillRect(x-10, y-13, box_w, box_h, GxEPD_WHITE);
   display.drawRect(x-10, y-13, box_w, box_h, GxEPD_BLACK);
   display.setFont(&FreeMonoBold9pt7b);
   display.setCursor(x-5, y); display.print(header); 
   Serial.println(header);Serial.print(": X_Header:");Serial.print(x-5); Serial.print(" / Y_Header:");Serial.print(y);
   Serial.print("; Min_Value: ");Serial.print(min_value);Serial.print(" / Max_Value: ");Serial.println(max_value);
   
   //Balkendiagramm invertiert ohne max Begrenzung VORSICHT!!!
   /*
   for (int i = 0; i < 14; i++){
      int delta = 45 - ((daten->Stack[i])-min_value);
      display.fillRect(x2+i*5,  y+2, 4, 45,        GxEPD_BLACK);//1
      display.fillRect(x2+i*5,  y+2, 4, (45-delta),GxEPD_WHITE);//1
   }
   */
   
   //Liniendiagramm V1
   /*
   for (int i = 0; i < 13; i++){
      int data1 = ((daten->Stack[i])-min_value);
      int data2 = ((daten->Stack[i+1])-min_value);
      Serial.print(";Data1:");Serial.print(data1);Serial.print("/ Data2:");Serial.print(data2);
      Serial.print("/ x_Start:");Serial.print(x2+i*5); Serial.print("/ y_Start:");Serial.print(y2+data1);Serial.print("/ x_Ende:");Serial.print(x2+((i+1)*5));Serial.print("/ y_Ende:");Serial.println(y2+data2);
      display.drawLine(x2+(i*5), y2+data1, x2+((i+1)*5), y2+data2, GxEPD_BLACK);//Ursprungslinie
      display.drawLine(x2+(i*5), y2-1+data1, x2+((i+1)*5), y2-1+data2, GxEPD_BLACK);//Linienverstärkung um 1 nach unten versetzt
      display.drawLine(x2+(i*5), y2-2+data1, x2+((i+1)*5), y2-2+data2, GxEPD_BLACK);//Linienverstärkung um 2 nach unten versetzt
      
   }*/
   //Liniendiagramm V2
   if (max_value - min_value !=0){//nicht durch 0 teilen
      //all save
   }
   else{ //Teile niemals durch Null
     min_value = min_value - 1;
     daten->Stack[0] = daten->Stack[0] -1;
   }
       for (int i = 0; i < 13; i++){
          float data_a = ((float)(max_value - constrain(daten->Stack[i], min_value, max_value))) / ((float)(max_value - min_value));//Serial.print(";Data_a:"); Serial.print(data_a); //constrain prüft ob Werte im Wertebereich
          float data_b = ((float)(max_value - constrain(daten->Stack[i+1], min_value, max_value))) / ((float)(max_value - min_value));// Serial.print(";Data_b:"); Serial.print(data_b); 
          int data1 = data_a * range;//Serial.print(";Data1:");Serial.print(data1);
          int data2 = data_b *range;//Serial.print("/ Data2:");Serial.print(data2);
          
          //Serial.print("/ x_Start:");Serial.print(x2+i*5); Serial.print("/ y_Start:");Serial.print(y2+data1);Serial.print("/ x_Ende:");Serial.print(x2+((i+1)*5));Serial.print("/ y_Ende:");Serial.println(y2+data2);
          display.drawLine(x2+(i*5), y2+data1, x2+((i+1)*5), y2+data2, GxEPD_BLACK);//Ursprungslinie
          display.drawLine(x2+(i*5), y2-1+data1, x2+((i+1)*5), y2-1+data2, GxEPD_BLACK);//Linienverstärkung um 1 nach unten versetzt
          display.drawLine(x2+(i*5), y2-2+data1, x2+((i+1)*5), y2-2+data2, GxEPD_BLACK);//Linienverstärkung um 2 nach unten versetzt
       }
   
   
   
}
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
